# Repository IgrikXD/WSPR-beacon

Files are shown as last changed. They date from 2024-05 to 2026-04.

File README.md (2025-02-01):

# WSPR-beacon

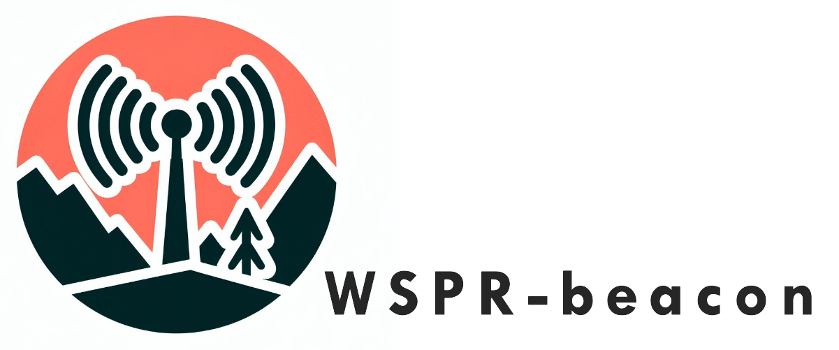
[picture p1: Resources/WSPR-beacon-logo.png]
WSPR-beacon


A small hardware device for transmitting WSPR messages based on the SI5351 IC. The device has a built-in TCXO to eliminate SI5351 frequency drift, a built-in GPS module for operation with active GPS antennas, transmission time synchronization and automatic QTH locator calculation, and a simple amplifier based on a single BS170 transistor ([_PCB version 1.0_](https://github.com/IgrikXD/WSPR-beacon/releases/tag/wspr-beacon-1.0)) or buffer amplifier based on a 74ACT244 IC ([_PCB version 2.0_](https://github.com/IgrikXD/WSPR-beacon/releases/tag/wspr-beacon-pcb-2.0)). PCB is made on based on SMD components and adapted for installation in an aluminum enclosure with dimensions 80 x 50 x 20 mm.

## Project support
[](https://nowpayments.io/donation/wsprbeacon)&nbsp;[](https://www.paypal.com/donate/?hosted_button_id=Q8PRFPXKKSDAQ)&nbsp;[](https://revolut.me/iharygxob)

Your support helps me continue developing open-source projects like [WSPR-beacon](#WSPR-beacon) and [Easy-SDR](https://github.com/IgrikXD/Easy-SDR), while also enabling the creation of new tools that benefit the community.

## Current development progress
[](https://oshwlab.com/igrikxd/wspr-beacon)&nbsp;  
[](https://github.com/IgrikXD/WSPR-beacon/actions/workflows/firmware-build.yml)&nbsp;  

The transmitted WSPR message's correctness was verified by decoding the transmission using a locally located Airspy R2 SDR receiver and the [WSJT-X](https://wsjt.sourceforge.io/wsjtx.html) application. Also, you can see the [results of testing the device during long-distance WSPR message transmission](./Device-test-report.md).

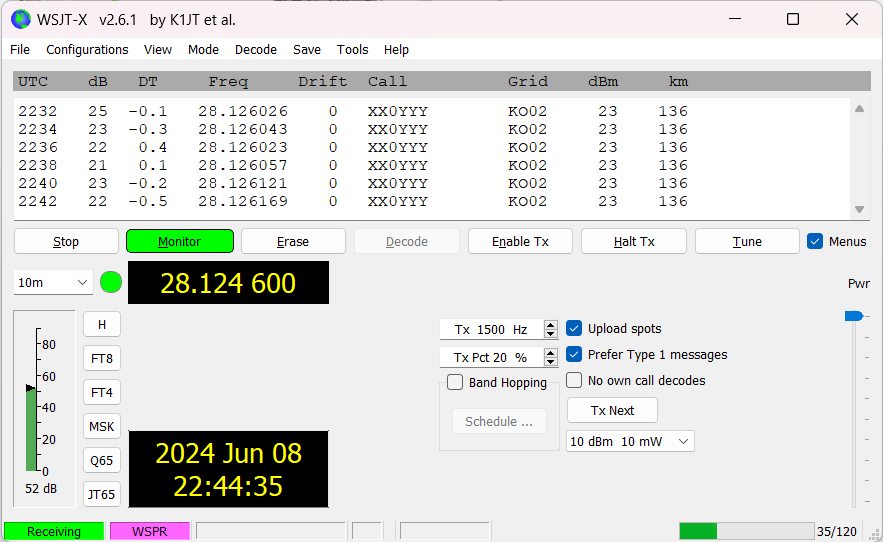
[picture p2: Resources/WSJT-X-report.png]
WSJT-X report


## Basic characteristics of the WSPR-beacon
**RF connectors:** SMA  
**Feed line:** 50 Ohm coaxial cable  
**GPS antenna type:** active, external  
**Maximum output power:** ~23 dBm  
**Supply voltage:** 5V, USB-B, fuse-protected  
**Current consumption:** 65 mA (_GPS antenna not connected_) / 80 mA (_GPS antenna connected_) / 92 mA (_TX mode_)  
**Used PCB Material:** FR-4  
**PCB thickness:** 1.6 mm  
**PCB copper weight:** 1 oz  

## How to use this repository?
The [Firmware](./Firmware/) folder contains software required for the device operation and [firmware instructions](./Firmware/README.md). The [Schematics](./Schematics/) directory contains the device schematic file in _.pdf_ format. The [Gerbers](./Gerbers/) directory contains files necessary for ordering PCB and side covers [fabrication at the factory](https://www.pcbway.com/project/shareproject/WSPR_beacon_2_0_472264d9.html).  

Additionally, you can find information about the [list of required components](./BOMs), [assembly guide](./Assembly-guide.md) and [operating instructions](./Usage-guide.md).

## Resources
[A Little WSPR Beacon (Aren’t They All Little?) – Dave Richards AA7EE](https://aa7ee.wordpress.com/2023/02/26/a-little-wspr-beacon-arent-they-all-little/)  
[Bifilar and trifilar PA](https://qrp-labs.com/ultimate3/u3info/u3sbifilar.html)  
[ESP WSPR – Simple and Inexpensive WSPR Transmitter - Ankara Telsiz ve Radyo Amatörleri Kulübü Derneği](https://antrak.org.tr/blog/esp-wspr-simple-and-inexpensive-wspr-transmitter/)  
[FDIM 2024 LOGIC IC TRANSMITTER CHALLENGE - Ankara Telsiz ve Radyo Amatörleri Kulübü Derneği](https://antrak.org.tr/haberler/fdim-2024-logic-ic-transmitter-challenge/)  
[HarrydeBug/WSPR-transmitters: Arduino firmware for ZachTek WSPR transmitters.](https://github.com/HarrydeBug/WSPR-transmitters/tree/master)  
[K1FM-WSPR-TX - GitHub](https://github.com/adecarolis/K1FM-WSPR-TX)  
[QRP Labs QRSS/WSPR TX Kit](https://qrp-labs.com/images/ultimate3s/assembly_u3s_r3_lt.pdf)  
[WSPR beacon – Projets radio](https://hamprojects.wordpress.com/2019/06/02/wspr-beacon/)  
[WSPR - Signal Identification Wiki](https://www.sigidwiki.com/wiki/WSPR)  

## Who helped me with the development of the project?
Great thanks to [PCBWay](https://pcbway.com) for manufacturing the PCBs for the project as a sponsored contribution.
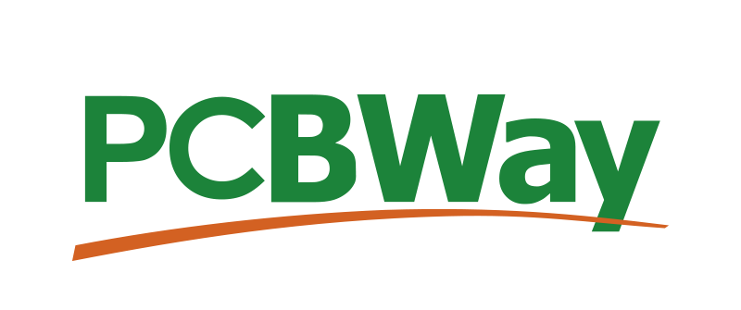
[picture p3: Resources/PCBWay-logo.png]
PCBWay-Logo


## How to contact me?
- E-mail: igor.nikolaevich.96@gmail.com
- Telegram: https://t.me/igrikxd
- LinkedIn: https://www.linkedin.com/in/igor-yatsevich/

You can also [contact me](https://t.me/igrikxd) to purchase preassembled devices.

[BTC-badge]: https://img.shields.io/badge/BTC-Make%20a%20donation-orange.svg?logo=bitcoin&style=for-the-badge
[PayPal-badge]: https://img.shields.io/badge/PayPal-Make%20a%20donation-blue.svg?logo=
[Revolut-badge]: https://img.shields.io/badge/Revolut-Make%20a%20donation-black.svg?logo=
[EasyEDA-badge]: https://img.shields.io/badge/EasyEDA%20WSPR--beacon-tested-greeen.svg?logo=easyeda&style=for-the-badge
[Firmware-build-badge]: https://img.shields.io/github/actions/workflow/status/IgrikXD/WSPR-beacon/firmware-build.yml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

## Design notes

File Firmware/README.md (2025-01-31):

# Firmware instruction

## Select the board:
Open [Arduino IDE](https://www.arduino.cc/en/software), go to "_Tools_" -> "_Board_", then select  "_Arduino Nano_".

## Choose the communication port:
Connect the device to your computer via USB cable. Then, in the "_Tools_" -> "_Port_" menu, select the target COM port.

## Verification of hardware operability after device assembly
After assembling the device, you can upload [firmware for testing the hardware](./wspr-beacon-hardware-test/wspr-beacon-hardware-test.ino).

> [!NOTE]
>This is an optional step, you can skip it. I recommend using this firmware if you encounter issues with the device's functionality when using the main wspr-beacon firmware.

This firmware checks the correctness of the LEDs initialization (_visual inspection_), SI5351 IC initialization, the correctness of the serial connection with the GPS module, and GPS data synchronization.

To get a report on the hardware functionality, [builld and upload](#firmware-building) the [wspr-beacon-hardware-test](./wspr-beacon-hardware-test/wspr-beacon-hardware-test.ino) firmware, open the "_Tools_" -> "_Serial Monitor_" in the Arduino IDE, and turn on the device.

**An example of an hardware test report:**
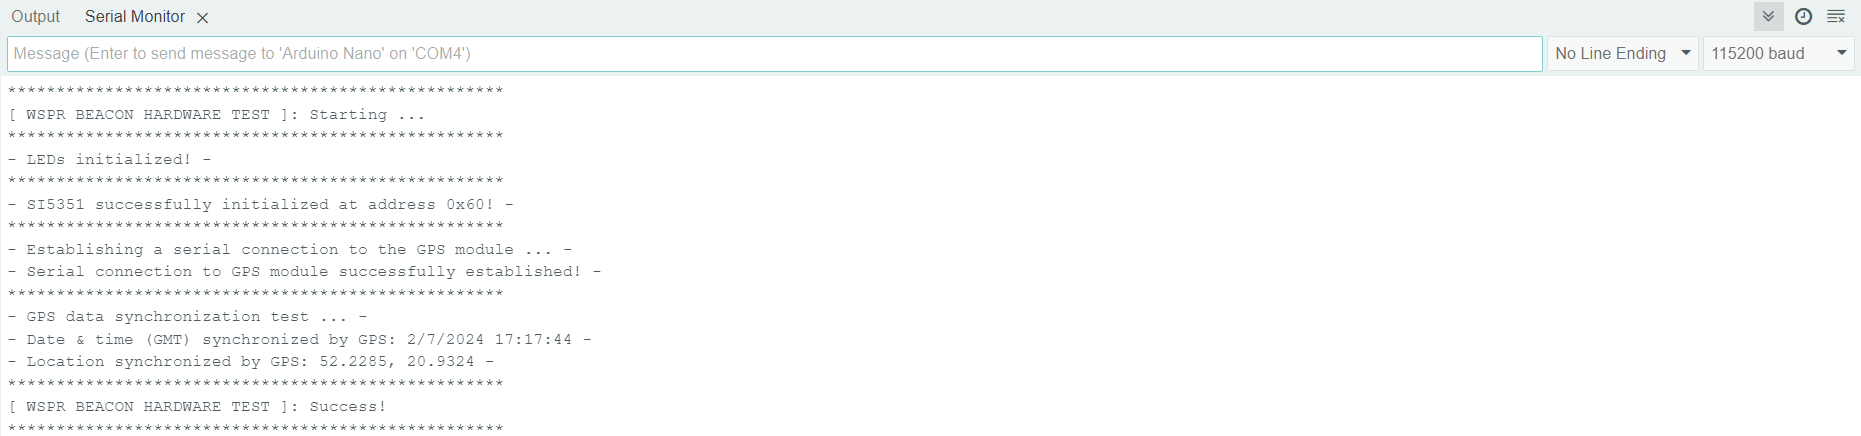
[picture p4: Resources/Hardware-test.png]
Hardware test


## I2C address of the SI5351:
By default, the SI5351 uses address **_0x60_** on the I2C bus. If necessary, you can change the I2C address of the SI5351 according to the datasheet of your instance:
```cpp
#define SI5351_I2C_ADDRESS         0x60
```

## SI5351 calibration:
For correct operation of the device you need to [calibrate](https://github.com/etherkit/Si5351Arduino/tree/master?tab=readme-ov-file#calibration) the SI5351 to calculate the difference between the uncalibrated actual frequency and the nominal output frequency. 

> [!NOTE]
>By default, the sketch for calibrating the SI5351 is set to operate with an output frequency of 10 MHz. If you do not have equipment that can operate at this frequency, you can use an SDR receiver like RTL-SDR.COM and a modified calibration sketch by changing the operating frequency to 28 MHz.

Upload this [sketch](https://github.com/etherkit/Si5351Arduino/blob/master/examples/si5351_calibration/si5351_calibration.ino) into the device and perform the calibration. Calibration is performed once for each pair of SI5351 and TCXO. The resulting calibration value must be changed in the [_wspr-beacon-1.1.ino_](./wspr-beacon-1.1/wspr-beacon-1.1.ino) file: 
```cpp
#define SI5351_CAL_FACTOR          2000
```

## Select the transmission frequency:
Uncomment the line with the band on which you want to perform the WSPR message transmission:
```cpp
// WSPR center frequency in Hz
// #define WSPR_DEFAULT_FREQ       137500ULL    // 0.1375 MHz - 2200m
// #define WSPR_DEFAULT_FREQ       475700ULL    // 0.4757 MHz - 600m
// #define WSPR_DEFAULT_FREQ       1838100ULL   // 1.8381 MHz - 160m
// #define WSPR_DEFAULT_FREQ       3570100ULL   // 3.5701 MHz - 80m
// #define WSPR_DEFAULT_FREQ       5288700ULL   // 5.2887 MHz - 60m
// #define WSPR_DEFAULT_FREQ       7040100ULL   // 7.0401 MHz - 40m
// #define WSPR_DEFAULT_FREQ       10140200ULL  // 10.1402 MHz - 30m
// #define WSPR_DEFAULT_FREQ       14097100ULL  // 14.0971 MHz - 20m
// #define WSPR_DEFAULT_FREQ       18106100ULL  // 18.1061 MHz - 17m
// #define WSPR_DEFAULT_FREQ       21096100ULL  // 21.0961 MHz - 15m
// #define WSPR_DEFAULT_FREQ       24926100ULL  // 24.9261 MHz - 12m
#define WSPR_DEFAULT_FREQ       28126100ULL  // 28.1261 MHz - 10m
// #define WSPR_DEFAULT_FREQ       50294500ULL  // 50.2945 MHz - 6m
// #define WSPR_DEFAULT_FREQ       144490000ULL  // 144.4900 MHz - 2m
```

> [!NOTE]
>At this step you select the center frequency. Each transmission cycle is performed at a randomly selected frequency within a range of +/- 100 Hz from the center frequency.

## Add WSPR message data:
Enter your amateur radio call sign to generate a correct WSPR message:
```cpp
#define WSPR_CALL                 "XX0YYY"
```
There is no need to specify your QTH locator, it will be calculated automatically by _void setQTHLocator()_ function based on actual GPS data.

## Firmware building:
Before building the firmware using Arduino IDE, you **need to install all the required dependencies**. You can automatically install all the necessary dependencies using Arduino CLI. Download and extract the [latest version of Arduino CLI](https://downloads.arduino.cc/arduino-cli/arduino-cli_latest_Windows_64bit.zip) into the directory containing the firmware you want to build. Run the following command to automatically download dependencies and build the firmware:
```powershell
./arduino-cli compile --export-binaries
```

## Upload an firmware:
Click the "_Upload_" button in the Arduino IDE to build and upload firmware to the device.

Alternatively, you can upload the precompiled _.hex_ file (_located in the build/arduino.avr.nano directory_) directly to the device using Arduino CLI:
```powershell
./arduino-cli upload --input-file build/arduino.avr.nano/<FIRMWARE_NAME>.hex --port <TARGET_PORT> --verify
```

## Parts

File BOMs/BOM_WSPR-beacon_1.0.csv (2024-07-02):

ID | Name | Designator | Footprint | Quantity | Manufacturer Part | Manufacturer | Supplier | Supplier Part
1 | CR1220-2 | B1 | BAT-SMD_CR1220-2 | 1 | CR1220-2 | Q&J | LCSC | C70381
2 | 100n | C1,C6,C7,C8,C11,C13,C15,C16,C19 | 0805 | 9 | CC0805JRX7R9BB104 | YAGEO | LCSC | C111492
3 | 10u | C2 | CASE-A_3216 | 1 | TAJB107M010RNJ | Kyocera AVX | LCSC | C7171
4 | 100u | C3,C18 | CASE-B_3528 | 2 | TAJB107M010RNJ | Kyocera AVX | LCSC | C7196
5 | 22p | C4,C5,C9,C10 | 0805 | 4 | CC0603JRNPO9BN220 | YAGEO | LCSC | C105620
6 | 10u | C12 | 0805 | 1 | CL21A106KOQNNNE | Samsung Electro-Mechanics | LCSC | C1713
7 | 100p | C14 | 0805 | 1 | C2012C0G2A101JT000N | TDK | LCSC | C76633
8 | 10n | C17,C20 | 0805 | 2 | 0805B103J500NT | Guangdong Fenghua Advanced Tech | LCSC | C24666
9 | PTC, 600 mA, 6V | F1 | F0805 | 1 | BSMD0805-030-6V | BHFUSE | LCSC | C22378354
10 | TX OUT | J1 | SMA-EDGE | 1 | BWSMA-KE11 | BAT WIRELESS | LCSC | C5250058
11 | GPS ANT | J2 | SMA-EDGE | 1 | BWSMA-KE11 | BAT WIRELESS | LCSC | C5250058
12 | 47n | L1 | 0805 WITHOUT MASK | 1 | FHW0805UC047JGT | FH (Guangdong Fenghua Advanced Tech) | LCSC | C113330
13 | RED | LED1 | LED-0805 | 1 | F.0805.00006/P2-0805R1TS2-08T-002 | TUOZHAN | LCSC | C7496834
14 | GREEN | LED2,LED3 | LED-0805 | 2 | NCD0805G1 | Foshan NationStar Optoelectronics | LCSC | C84260
15 | BS170 | Q1 | TO-92-3_L4.9-W3.7-P1.27-L | 1 | BS170 | onsemi(安森美) | LCSC | C111691
16 | 1M | R1 | 0805 | 1 | RC0805FR-071ML | YAGEO | LCSC | C107700
17 | 10k | R2 | 0805 | 1 | 0805WAD1002T5E | Uniroyal Elec | LCSC | C169071
18 | 1k | R3 | 0805 | 1 | 0805W8F1001T5E | UNI-ROYAL(Uniroyal Elec) | LCSC | C17513
19 | 3.3k | R4,R5,R8 | 0805 | 3 | 0805W8F3301T5E | UNI-ROYAL(Uniroyal Elec) | LCSC | C26010
20 | 4.7k | R6,R7 | 0805 | 2 | 0805W8F4701T5E | UNI-ROYAL(Uniroyal Elec) | LCSC | C17673
21 | 3.3k | R9 | RES-ADJ-SMD_VG039NCH | 1 | VG039NCHXTB332 | HDK(Hokuriku Elec Industry) | LCSC | C128554
22 | MTS-101/102-C3 | SW1 | MTS-102-C3 | 1 | 1MS1T2B4M6QES | Dailywell | LCSC | C545199
23 | FT37-43-Bifilar 10T | T1 | BIFILAR_FT37-43 | 1 | 5943000201 | Fair-Rite (Amidon) | RF Microwave | FT-37-43
24 | LM1117IMPX-3.3/NOPB | U1 | SOT-223_L6.5-W3.5-P2.30-LS7.0-BR | 1 | LM1117IMPX-3.3/NOPB | TI(德州仪器) | LCSC | C23984
25 | CH340G | U2 | SOIC-16_150MIL | 1 | CH340G | Jiangsu Qin Heng | LCSC | C14267
26 | ATMEGA328P-AU | U3 | TQFP-32_7X7X08P | 1 | ATMEGA328P-AU | Microchip Tech | LCSC | C14877
27 | ATGM336H-5N31 | U4 | GPSM-SMD_ATGM336H-TR | 1 | ATGM336H-5N31 | ZHONGKEWEI | LCSC | C90770
28 | 25MHz TCXO | U5 | OSC-SMD_4P-L3.2-W2.5-BL_7Q26000001 | 1 | SX3T25.000B010J020S | Shenzhen SCTF Elec | LCSC | C5180004
29 | Si5351A-A-GT | U6 | MSOP10 | 1 | SI5351A-B-GTR | SKYWORKS/SILICON LABS | LCSC | C504891
30 | USB-B | USB1 | USB TYPE B | 1 | C46392 | Jing Extension of the Electronic Co. | LCSC | C46392
31 | 12MHz | X1 | CRYSTAL-SMD_4P-L3.2-W2.5-BL_SIT8008BI | 1 | CF4012M00020001 | HUAXIN(华昕) | LCSC | C7294551
32 | 16MHz | X2 | CRYSTAL-SMD_4P-L3.2-W2.5-BL_SIT8008BI | 1 | CF4016M00012001 | HUAXIN(华昕) | LCSC | C7294559

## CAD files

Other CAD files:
Enclosure-models/WSPR-beacon-side-covers.dwg

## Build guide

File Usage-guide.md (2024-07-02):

# WSPR-beacon usage guide

## Device preparation
[Assemble the device](./Assembly-guide.md) and [upload the firmware](./Firmware/). Connect active GPS antenna, antenna for WSPR message transmission and USB-B cable for device power supply.  

> [!NOTE]
>It is recommended to use full-size antennas for a specific transmission range, as their efficiency is significantly superior to that of wideband and compact antennas. Also, it is recommended to use bandpass filters that suppress unwanted signals outside the operating range (the SI5351 emits unwanted harmonics along with the main signal emission at the operating frequency).

## Device usage
The device operates in fully automatic mode. Turn on the device by switching the **_SW1_** toggle switch position. After switching on the device the **_green LED (ON)_** should light up, which means that the device is working correctly and the initialization process has started. 

### Hardware initialization
Initialization of the hardware is performed in the _void setup()_ function and is executed only once, when the device is started.  

By default, the SI5351 is initialized at I2C address 0x60. If no device is detected at this address, an initialization error is indicated by the LED (_the **red LED (TX)** blinks three times_) and the device subsequently restarts. **If you encounter any problems at this stage - make sure that your SI5351 instance really has I2C address 0x60!** If necessary, you can [change the value of the I2C address of the SI5351](https://github.com/IgrikXD/WSPR-beacon/tree/master/Firmware#i2c-address-of-the-si5351) in the firmware source code.

The GPS module used in the device operates using a software-implemented serial port. Initialization of the GPS module starts with checking if any information is available from the GPS receiver on the virtual serial port. If no data is received within "_GPS_INIT_MAX_TIME_" - an GPS module initialization error is indicated by the LED (_the **red LED (TX)** blinks three times_) and the device will be rebooted. 

If the connection is successfully initialized, date and time synchronization is performed based on the data received from the GPS module. The device performs "_GPS_SYNC_ATTEMPTS_" attempts to synchronize GPS data with a delay of "_GPS_SYNC_DELAY_". If all synchronization attempts fail, an GPS data synchronization error is indicated by the LED (_the **red LED (TX)** blinks three times_) and the device is rebooted.  

> [!WARNING]
>The device will not transmit WSPR messages until the time and coordinates are synchronized!  

Successful completion of GPS data synchronization is signaled by a **_green LED (GPS)_**, after which the device proceeds to generate a buffer containing a WSPR message for transmission.

The calculation of your QTH locator is performed once during the device initialization based on current GPS data. The QTH locator is calculated during the execution of the _void encodeWSPRMessage(const TinyGPSPlus& gpsDataObj)_ function using the _void setQTHLocator(const TinyGPSPlus& gpsDataObj, char qthLocator[])_ function and is immediately written to the buffer responsible for forming the transmitted WSPR message. **Subsequently, during the operation of the device, the QTH locator is not updated!**  

### WSPR message transmission
Transmission of WSPR messages is performed in an infinite loop _void loop()_ every even minute (_00:00, 00:02, 00:04, ..._). **Each transmission cycle is executed at a randomly selected frequency within the range of +/- 100 Hz from the center operating frequency.** During the WSPR message transmission, the **_red LED (TX)_** lights up and goes out immediately after the transmission is completed. After completion of the transmission cycle, the device re-synchronizes the time based on the current GPS data values.

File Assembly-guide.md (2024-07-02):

# Assembly guide

## PCB requirements
When manufacturing the PCB, use FR-4 material with a thickness of 1.6 mm and a copper weight oequal to 1 oz. Although this is not the best material for radio frequency equipment, it is the most popular and widely available. The use of FR-4 material is necessary to ensure the wawe impedance of the RF line is 50 ohms. Failure to meet this requirement will result in additional signal loss during device operation. The impedance calculations were performed for a material with a dielectric constant Er = 4.6 (FR-4) using the [Saturn PCB Design V7.08](http://www.saturnpcb.com/pcb_toolkit/) toolkit.

## Requirements for Atmega328

When using Atmega328 distributed as individual electronic components, you will encounter a firmware upload error:
```log
avrdude: stk500_recv(): programmer is not responding 
avrdude: stk500_getsync() attempt 1 of 10: not in sync: resp=0x88
```

This is because **Atmega328 chips distributed as individual electronic components do not have a built-in bootloader** – they are completely blank chips, making it impossible to upload firmware via the Arduino IDE. Since the WSPR beacon PCB does not have an ISP interface, **you need to use an Atmega328 chip with a pre-flashed bootloader when assembling the device**. The best solution in this situation might be to move the Atmega328 chip from a ready-made Arduino Nano board. Such a chip already has a pre-flashed bootloader, allowing you to upload the WSPR beacon firmware without any problems.

## Winding a bifilar transformer
For winding a bifilar transformer, I recommend you use the instructions from [QRP-Labs: "10-turn bifilar-winding option"](https://qrp-labs.com/images/ultimate3s/assembly_u3s_r3_lt.pdf).  

**The only difference lies in the method of soldering the bifilar transformer on the PCB:** you need to solder the end of the primary winding to the beginning of the secondary winding - this will be one of the transformer leads, which is soldered as the central contact of the transformer on the PCB.

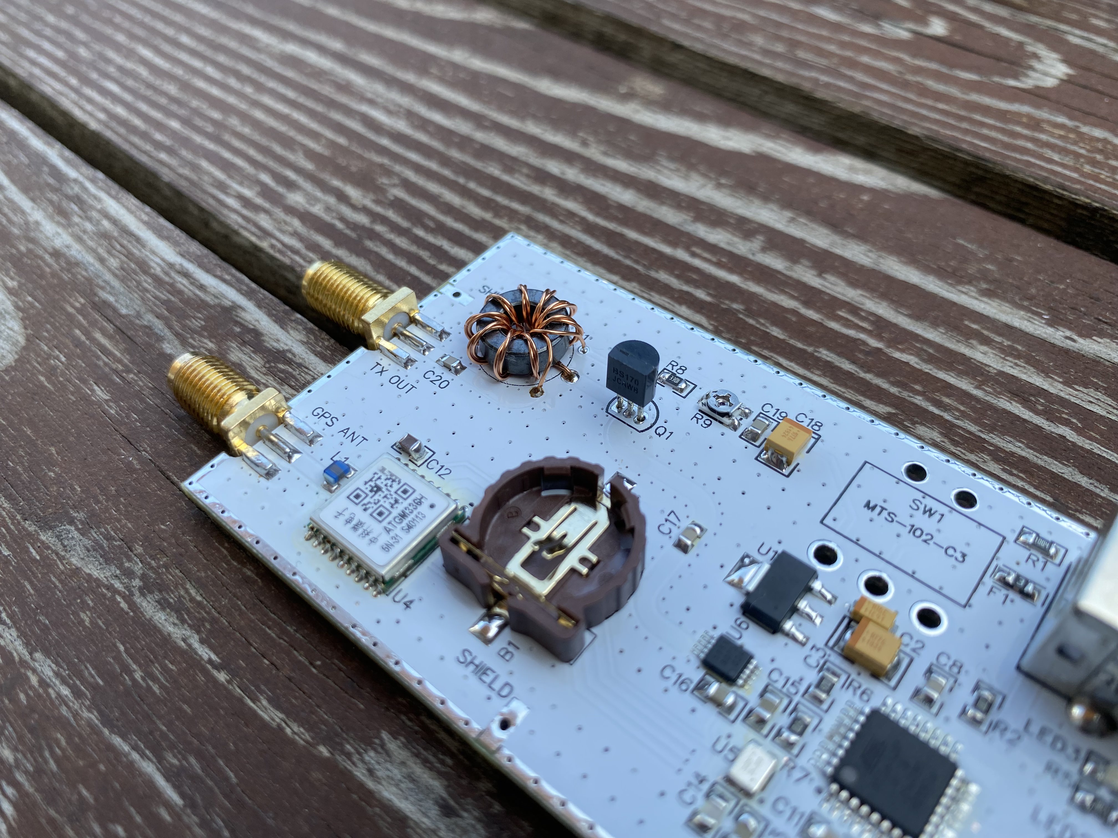
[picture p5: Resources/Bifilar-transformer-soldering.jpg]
Bifilar transformer soldering
  

## Installing the PCB in the aluminum enclosure

To assemble the device, an aluminum case with dimensions 80 x 50 x 20 mm is used.

Install the PCB in one part of the enclosure by placing it on the appropriate chassis. Screw on the side covers of the chassis and tighten the nuts on the SMA connectors - this will secure the PCB and allow you to mark the locations for cutting the holes for the SW1 toggle switch. Take the SW1 toggle switch and place it in the mounting location on the PCB. The area where the toggle switch contacts the side of the case must be milled (_you can use a 6mm round file_) so that the toggle switch can be positioned and soldered to the PCB.  

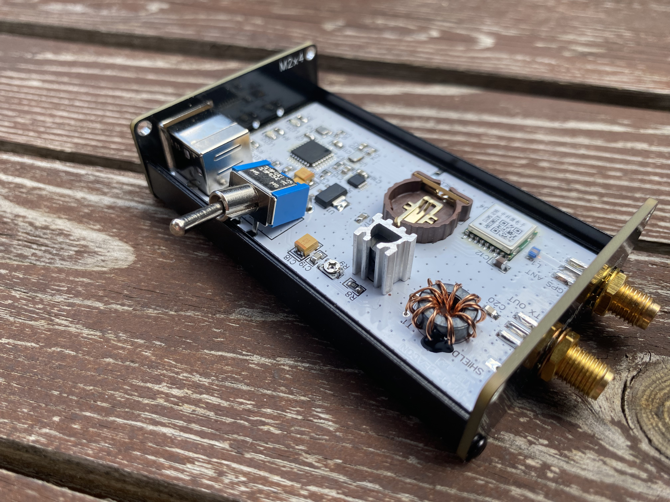
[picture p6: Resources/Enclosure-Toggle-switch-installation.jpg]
Toggle switch installation
  

Mark the same point on the top of the aluminum enclosure.  

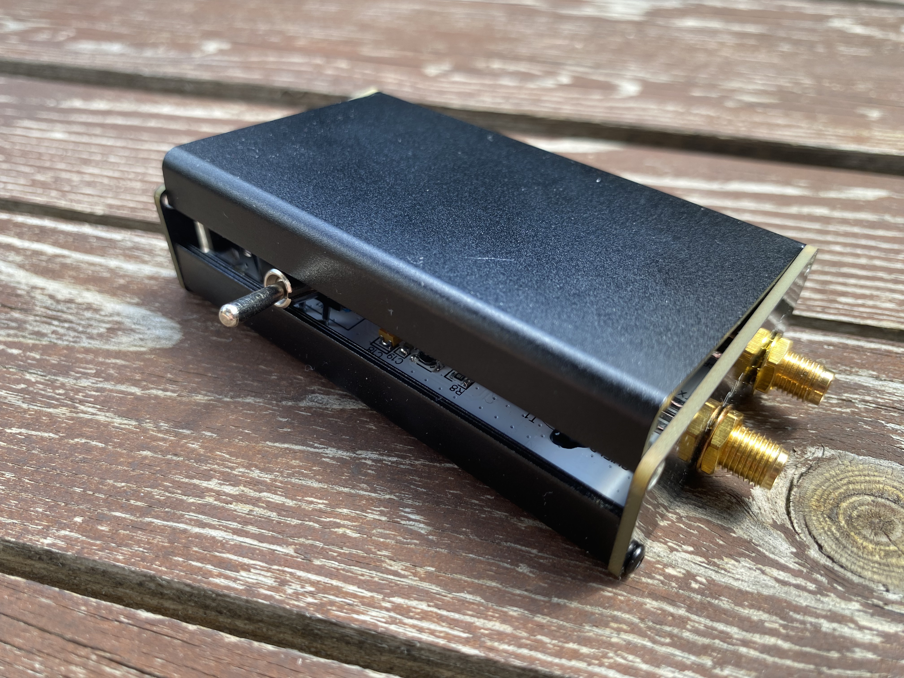
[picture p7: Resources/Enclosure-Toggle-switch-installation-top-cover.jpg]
Toggle switch installation, top cover
  

Unscrew the side covers of the enclosure, remove the PCB and use a file to cut the hole for the toggle switch to the correct depth. After cutting, put the PCB back into the case and check how freely the toggle switch fits into the cut-out hole. If you are unable to install the toggle switch correctly, repeat the above steps until optimal results are achieved.  

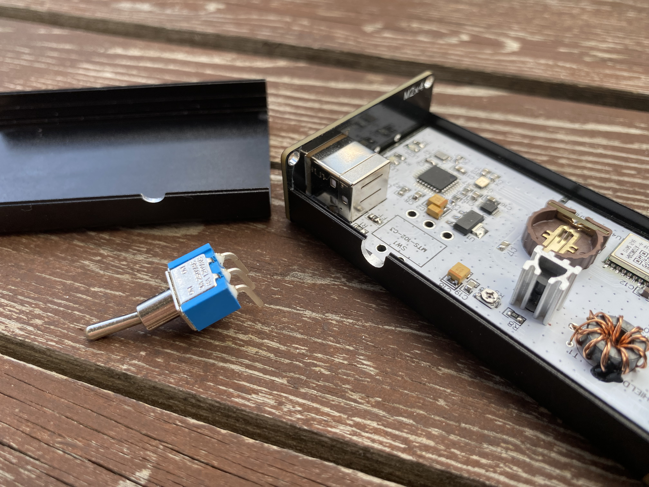
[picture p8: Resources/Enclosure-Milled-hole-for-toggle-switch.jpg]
Milled hole for toggle switch
 

Insert the PCB back into the enclosure, screw on the side covers of the aluminum enclosure, and tighten the nuts on the SMA connectors, then solder the SW1 toggle switch.

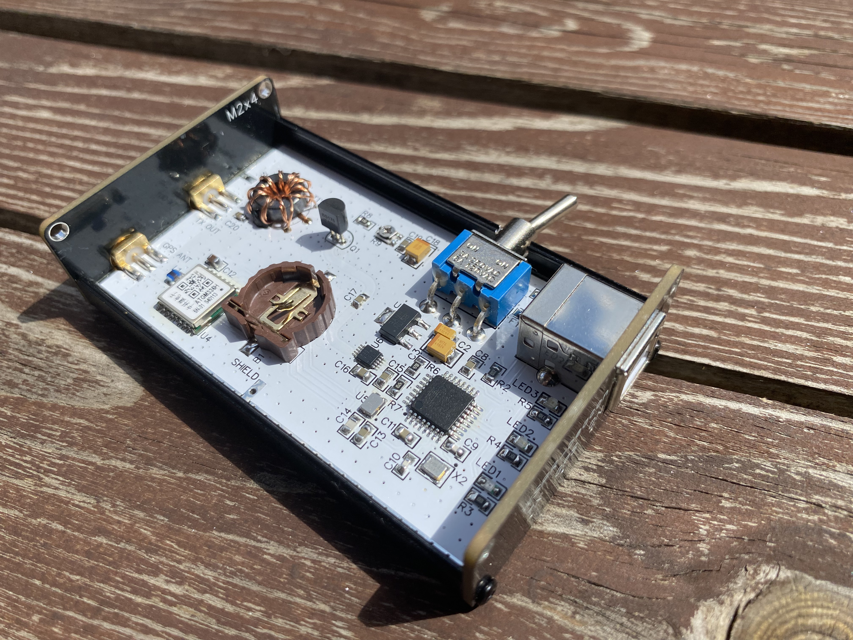
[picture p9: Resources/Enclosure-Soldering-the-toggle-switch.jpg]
Soldering the toggle switch
  

After soldering clean the PCB to remove any flux residues. Screw the top cover of the aluminum enclosure. Now the device is ready to work.

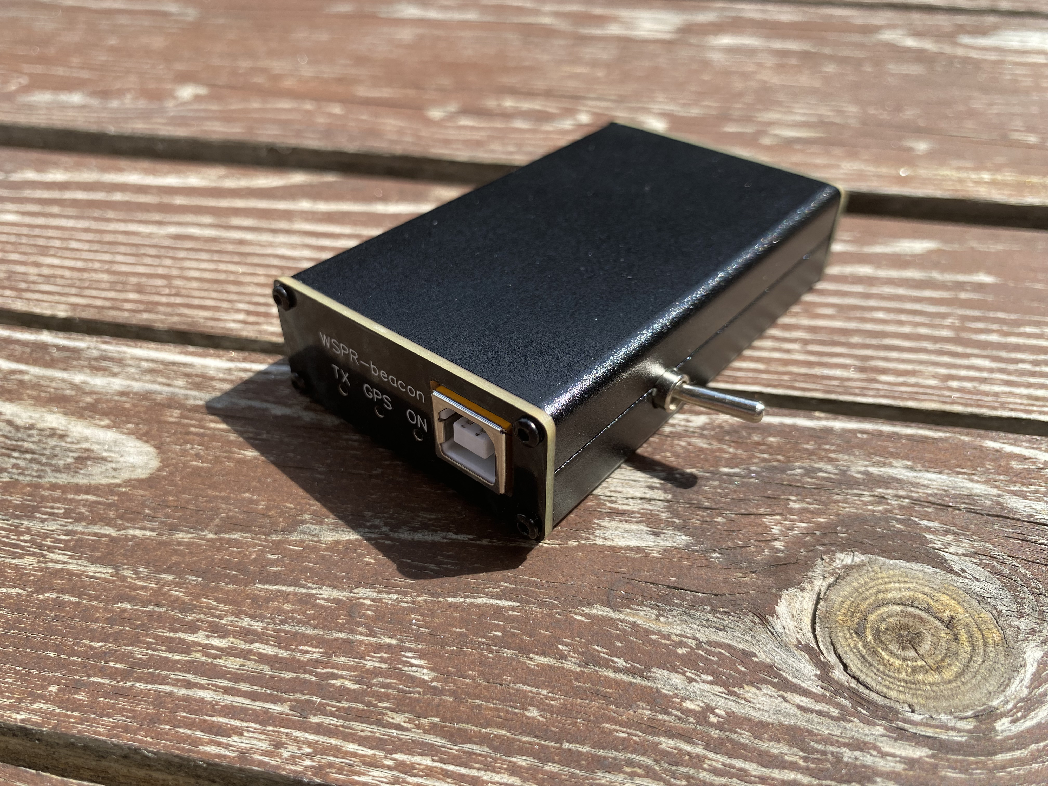
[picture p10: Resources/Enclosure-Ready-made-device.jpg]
Ready-made device
  

## Adjusting the output amplifier
> [!NOTE]
> Only applicable for [PCB version 1.0](https://github.com/IgrikXD/WSPR-beacon/releases/tag/wspr-beacon-1.0)!

To adjust the output amplifier, I recommend you use the instructions from [QRP-Labs: "PA bias set-up"](https://qrp-labs.com/images/ultimate3s/assembly_u3s_r3_lt.pdf).

For additional cooling of the BS170 transistor, you can use an off-the-shelf aluminum heatsink for TO-92 package transistors.  

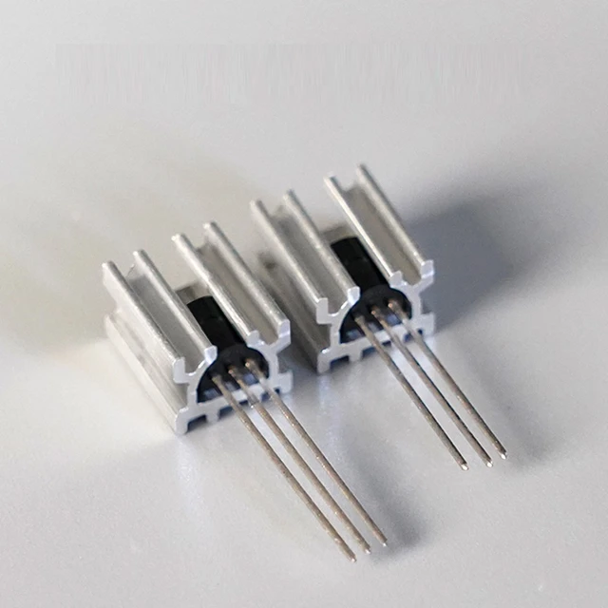
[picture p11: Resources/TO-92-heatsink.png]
TO-92 heatsink


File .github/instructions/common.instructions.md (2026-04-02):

---
applyTo: "**/*"
---

# Project description
The project is an open implementation of a hardware-software platform used for transmitting amateur WSPR messages.

The project is divided into the following main logical directories:
- `App/` - contains the source code of the **BEACON.App** user application, used with devices based on the **ESP32-C3 SoC**. It also includes integration tests, unit tests, and build documentation for different operating systems.
- `Firmware/` - contains firmware-related files for devices based on the **ATmega328P MCU** and the **ESP32-C3 SoC**. For ATmega328P MCU, it includes firmware source code, build documentation, and end-user documentation. For ESP32-C3 SoC, it contains firmware version metadata and download links for binary images. The ESP32-C3 SoC firmware is proprietary and stored in a separate private repository that is not accessible to end users.
- `PCB/` - contains Gerber manufacturing files, schematics, bills of materials (_BOM_), and manual assembly instructions for a specific device revision.
- `Resources/` - contains graphical assets used in the project documentation.

The project is developed using a modular architecture with a clear separation of responsibilities between individual components.

# Critical rules
- **Never fabricate.** Do not invent information, do not make assumptions, and do not speculate about code, APIs, or functionality that you have not explicitly verified by reading the documentation files or performing searches.
- **Data-driven development.** All created solutions or responses must be based on factual data from technical documentation or search results.
- **Ask if something is unclear.** If any information is ambiguous, requires confirmation, or has multiple possible interpretations, clarify the points you need before continuing.
- **Availability of MCP.** If the required MCP plugin is unavailable, explicitly inform the user and provide instructions on how to enable it.
- **eFuse Safety.** Writing to eFuse is a permanent operation. Before suggesting any command that modifies eFuses (e.g., via espefuse.py), explicitly warn the user that this action is irreversible and could brick the device if keys or parameters are incorrect.
- **Look before you leap.** Before implementing a new functionality, search the `App/` (_if changes requested for the BEACON.App_) or `Firmware/` (_if changes requested for the firmware_) directory for existing implementations. Reuse existing modular components to maintain architectural consistency.

# Related instruction files
- [beaconapp.instructions.md](./beaconapp.instructions.md) — **BEACON.App** architecture, threading model, logging, testing conventions, and auxiliary tools (_applies to `App/**`_).
- [firmware.instructions.md](./firmware.instructions.md) — Firmware source code structure and build environment for ATmega328P MCU based and ESP32-C3 SoC based devices (_applies to `Firmware/**`_).
- [python.instructions.md](./python.instructions.md) — Python naming conventions, error handling, code formatting, docstrings, import ordering, type hints, and best practices (_applies to `**/*.py`_).

# Auxiliary tools
- **MCP (Model Context Protocol):** Use the MCP plugin to access multiple contexts of information, including project documentation, codebase, and external resources. Always specify the context you are referring to when providing information or asking questions. Available MCP servers:
  - **Context7:** Provides up-to-date technical documentation for libraries and APIs used in the project. For any question regarding relevant available API or protocol specifics, you must use this tool. Do not rely on your internal training data for API specs, as API revisions may vary.
  - **GitHub:** Provides access to GitHub repository operations such as managing issues, pull requests, branches, releases, and code search. For any tasks involving GitHub repository interactions, you must use this tool. When creating or updating pull requests and issues, always assign them to the author and apply appropriate [labels](https://github.com/IgrikXD/WSPR-beacon/labels). Refer to [CONTRIBUTING.md](../../CONTRIBUTING.md) for detailed project contribution guidelines, including rules for opening issues, submitting pull requests, branch naming conventions, and code review process.

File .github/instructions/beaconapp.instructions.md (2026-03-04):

---
applyTo: "App/**"
---

> Python coding conventions (_naming, error handling, formatting, type hints_) are defined in [python.instructions.md](./python.instructions.md).

## BEACON.App source code
The **BEACON.App Python source code** is located in the `App/` directory and is responsible for:
- Supporting communication between the hardware device (_WSPR-beacon_) and the desktop user application (_BEACON.App_) via USB (_Serial_) or Wi-Fi (_WebSocket_) connections using control commands in JSON format.
- Generating valid JSON control commands sent to the device (_WSPR-beacon_) to set the active transmission mode, run self-checks, and configure device parameters (_calibration, Wi-Fi connection_).
- Providing a device firmware update mechanism both via USB and through OTA updates.
- Ensuring the reliability of the user application by implementing integration and unit tests to verify the functionality of implemented features.

The application source code is organized into the following subpackages within `App/beaconapp/`:
- `transports/` - transport layer implementations.
- `ui/` - user interface widgets and graphical resources.
- `tests/` - test suite, split into `unit/` and `integration/` subdirectories.

**BEACON.App** is designed to work only with devices based on the **ESP32-C3 SoC**. Devices based on the **ATmega328P MCU** are not supported!

### Build environment
- **Build system (_GitHub Actions_):** PyInstaller.
- **Build configuration file (_Linux, GitHub Actions_):** `.github/workflows/app-build-linux.yml`.
- **Build configuration file (_Windows, GitHub Actions_):** `.github/workflows/app-build-windows.yml`.
- **Test configuration file (_GitHub Actions_):** `.github/workflows/app-tests.yml`.
- **Python standard:** 3.12.

# Async and threading
The application uses a two-thread architecture:
- **Main thread** runs the Tkinter/customtkinter event loop (_UI_). All UI manipulations must happen on this thread.
- **Asyncio thread** is a dedicated daemon thread that owns an asyncio event loop and calls `loop.run_forever()` to handle USB (_Serial_) and Wi-Fi (_WebSocket_) transport I/O.

Communication between threads:
- **Main -> asyncio**: Use `asyncio.run_coroutine_threadsafe()` to schedule coroutines, or `loop.call_soon_threadsafe()` for synchronous calls into the event loop.
- **Asyncio -> UI**: Transport layers decode incoming JSON messages and invoke registered callback handlers via `Device._call_handlers()`. Callbacks that update UI must use `widget.after(0, lambda: ...)` to marshal the call onto the main thread.

The UI registers its callbacks for device message types via `Device.set_device_response_handlers()`, forming a message-driven architecture where the `Device` class acts as the bridge between transports and UI.

Threading primitives:
- Use `asyncio.Queue` for outgoing message passing between the main thread and the asyncio transmit loop. `asyncio.Queue` is not thread-safe; the main thread must enqueue items via `loop.call_soon_threadsafe(queue.put_nowait, item)` to ensure the operation executes on the asyncio thread.
- Use `threading.Lock` for protecting shared state (_e.g., connection state_).
- Use `threading.Event` for cross-thread synchronization (_e.g., waiting for the event loop to start_).
- Use `threading.Thread(target=..., daemon=True)` for background work dispatch (_e.g., USB firmware update_).
- Any new functionality that may block the UI thread or the asyncio thread must be executed in a separate thread to prevent freezing the interface or stalling transport I/O.

# Logging
- Use the logging facade in `logger.py` (_`log_ok`, `log_error`, `log_warning`, `log_rx_message`, `log_tx_message`_) instead of calling the `logging` module or `print()` directly.
- Debug mode is controlled by the `--debug` CLI argument.

# Testing conventions
- Any new functionality must be covered by unit tests. Features that involve hardware interaction must also be covered by integration tests.
- Use **pytest** as the primary test framework.
- Mark every unit test with `@pytest.mark.unit` and every integration test with `@pytest.mark.integration`.
- Use `@pytest.mark.parametrize` for data-driven tests. Place `@pytest.mark.parametrize` **before** the marker decorator (_e.g., `@pytest.mark.unit`_) in the decorator stack.
- Use `tmp_path` (pytest built-in) for temporary file operations in tests. Use `os.path.dirname(__file__)` for loading test fixture files.
- Gate integration tests with `@pytest.mark.skipif(not find_device(), reason="...")` when they require a connected hardware device.
- Add Google-style docstrings to test functions to describe what is being verified.
- Use `pytest.raises()` with an optional `match=` parameter for exception testing.
- Use **pytest-cov** for measuring test coverage. Run coverage with `python -m pytest --cov=beaconapp --cov-config=pytest.ini`. Coverage configuration is defined in `App/pytest.ini` and excludes test files, `__init__.py`, and `main.py` (_application entry point_) to focus on business logic coverage.

# Auxiliary tools
- **pip**: Package manager for installing project dependencies. Runtime dependencies are listed in `App/requirements.txt`, development dependencies in `App/requirements-dev.txt`.
- **flake8**: The project uses flake8 with plugins for linting, code style enforcement, cyclomatic complexity checking, and static analysis (_bugbear, builtins, comprehensions, eradicate, simplify_). Refer to the `App/.flake8` file for the configuration.

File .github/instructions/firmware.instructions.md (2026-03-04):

---
applyTo: "Firmware/**"
---

## Firmware source code
The firmware source code is located in the `Firmware/` directory and is split into separate subdirectories depending on the device architecture used.

### ATmega328P MCU-based devices
The firmware source code is located in the `Firmware/ATmega328P-based/` directory and is responsible for:
- Generating a user-predefined WSPR message based on the amateur radio callsign and the transmit power in dBm, for subsequent transmission on a predefined frequency.
- Calculating the QTH locator used when forming the WSPR message using data received from the onboard GPS module.
- Synchronizing the transmission timing of WSPR messages using data received from the onboard GPS module.
- Adding a random transmit frequency offset to prevent collisions with other WSPR transmitters operating in the same area.
- Indicating possible errors via the built-in LED indicators.
- Testing the functionality of the device's internal components and presenting the test results to the user using a separately flashed firmware image.

Devices based on the ATmega328P MCU do not support reconfiguration during operation. To apply new operating parameters (_amateur radio callsign, transmit power, transmission frequency_), the user must manually modify the firmware source code, rebuild it, and re-flash the device.

#### Build environment
- **Build system (_GitHub Actions_):** Arduino CLI.
- **Build configuration file (_GitHub Actions_):** `.github/workflows/firmware-build.yml`.

### ESP32-C3 SoC-based devices
The firmware is distributed to end users only in a signed and pre-encrypted form, which implies that it can be executed only on hardware devices that have explicitly provisioned Secure Boot v2 signing and Flash Encryption AES-XTS keys stored in the ESP32-C3 SoC eFuse.

In turn, the `Firmware/ESP32C3-based/` directory contains a `latest-stable.json` file with information about the current firmware version, download links to the binary files (_used for firmware updates via the BEACON.App application over USB and via the OTA mechanism_), and a SHA-256 checksum for validating the provided binary images.

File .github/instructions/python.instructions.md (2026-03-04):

---
applyTo: "**/*.py"
---

# Naming conventions
- Use `snake_case` for variables, functions, and methods.
- Use `ALL_CAPS` for module-level constants (_e.g., `LOCK_DIR`, `API_ENDPOINT`_).
- Use `PascalCase` for classes and enums (_e.g., `SomeClass`, `SomeEnum`_).
- Use single-underscore prefix (`_`) for private methods and instance attributes (_e.g., `_some_function`, `self._some_attribute`_).
- Use double-underscore prefix (`__`) for class-level private constants with name mangling (_e.g., `__SOME_VALUE`, `__SOME_VALUE_MAX_SIZE`_).

# Error handling
- Use custom exception classes nested inside the relevant class (_e.g., `SomeClass.SomeSpecificError`_) for domain-specific errors.
- Use `ValueError` for input validation failures.
- Use `try`/`except` with specific exception types. Log errors instead of re-raising (_in async/callback contexts_).
- Use `contextlib.suppress()` for non-critical exceptions that should be silently ignored (_e.g., `contextlib.suppress(OSError)`_).

# Code formatting
- Follow PEP 8 style guide for Python code formatting.
- Use blank lines to separate logical blocks of code for better readability.
- Use 4 spaces per indentation level. Do not use tabs.

# Comments
- Use Google-style docstrings (_triple-quoted strings_) to document functions and classes. Include `Args:`, `Returns:`, `Yields:`, and `Raises:` sections where applicable.
- Class-level docstrings are required for all classes, including widgets and test modules. Method-level docstrings are required for all public and private methods that perform non-trivial operations.
- For widget `__init__` methods that accept external dependencies (_e.g., `parent`, `device`, `config`_), add a docstring with an `Args:` section describing each parameter.
- Document class-level private constants using regular `#` comments placed above the constant. Do not use standalone triple-quoted string literals inside a class body for this purpose - they are not attached to the following assignment, do not appear in generated documentation, and create an unused string constant at class creation time.
- Use inline comments sparingly to explain non-obvious code sections. Avoid stating the obvious.
- Keep comments up to date with code changes to prevent confusion.
- Avoid using comments to disable code.

# Import ordering
- Follow PEP 8 import grouping: standard library first, then third-party, then local (`modulename.*`). Separate each group with a blank line.
- Within each group, place bare `import` statements before `from ... import` statements, each sub-group sorted alphabetically.

# Type hints
- Use type hints for function parameters and return types where applicable.
- Use `typing` module types (_`Optional`, `Dict`, `List`, `Set`, `Callable`, `Any`_) for complex annotations.
- Use modern union syntax (_`X | Y`_) where applicable.

# Best practices
- Use context managers (_`with` statements_) for resource management (_e.g., file handling, serial connections, threading locks_).
- Use list comprehensions and generator expressions for concise and efficient code where appropriate.
- Avoid using mutable global variables. Use module-level `ALL_CAPS` constants for configuration values.
- Always specify `encoding="utf-8"` when opening text files.
- Use f-strings for string formatting instead of `%` or `.format()`.
- Use `@dataclass` for data containers with manual `to_json()`/`from_json()` serialization methods. Dataclass fields must be typed.
- Use `Enum` for value enumerations.
- Use `ABC` + `@abstractmethod` for abstract interfaces.
- Use `@staticmethod` for utility methods that do not access instance or class state (_e.g., `Widgets` factory, `DataValidation` validators_).
- Use `@classmethod` for factory/deserialization methods (_e.g., `from_json`_).
- Use `widget.after(0, lambda: ...)` for thread-safe Tkinter/customtkinter UI updates from non-main threads.

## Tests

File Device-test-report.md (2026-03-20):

# WSPR-beacon device test report

This section provides information about the device's performance during long-distance WSPR message transmission. Data on transmitted and decoded WSPR messages are taken from the [WSPR Rocks!](http://wspr.rocks/)

For each transmission range, a visualized report with a list of all spots is available. To view the visualization, click on the distance in the "_Max distance to receiver_" column.

> [!NOTE]
>During testing of the device, the antenna used was tuned to the resonant frequency using the NanoVNA vector network analyzer.  
>
>**The efficiency of an antenna's performance largely depends on its installation conditions!** In addition to tuning the antenna to achieve the minimum SWR value, the quality of transmission is also influenced by: the height of the antenna installation, the orientation of the antenna in space, the presence of dense urban development with a large amount of electromagnetic interference, and the presence of dense forests absorbing emitted radio waves. **Please, when installing the antenna, to achieve maximum performance, consider all possible factors affecting the efficiency of radio transmission!**

**Power source used:** Mi Power Bank Pro PLM07ZM  
**Coordinates of the antenna installation site:** [52.1958, 20.7581](https://maps.app.goo.gl/dVwvhpxdYiYVqSht5)

### [PCB version 1.0](https://github.com/IgrikXD/WSPR-beacon/releases/tag/wspr-beacon-1.0) with BS170 field-effect transistor amplifier:

| Firmware version | TX frequency | TX time (CET) | PA bias | Used antenna | SNR | Drift | Max distance to receiver |
|---|---|---|---|---|-----|---|---|
| 1.0 | 5.2887 MHz | 21:02 - 21:32 | 2.508V  | [Windcamp Gipsy] | -22 | 0 | 3898 km |
| 1.0 | 7.0401 MHz | 19:04 - 19:34 | 2.508V  | [Windcamp Gipsy] | -16 | 0 | 2849 km |
| 1.0 | 10.1402 MHz  | 17:32 - 18:02 | 2.508V  | [Windcamp Gipsy] | -4  | 0 | 2849 km |
| 1.0 | 14.0971 MHz  | 15:10 - 15:40 | 2.508V  | [Windcamp Gipsy] | -26 | 0 | 1797 km |
| 1.1 | 5.2887 MHz | 21:36 - 22:06 | 2.508V  | [Windcamp Gipsy] | -23 | 0 | 3898 km |
| 1.1 | 7.0401 MHz | 19:38 - 20:08 | 2.508V  | [Windcamp Gipsy] | -21 | 0 | 2043 km |
| 1.1 | 10.1402 MHz  | 16:56 - 17:26 | 2.508V  | [Windcamp Gipsy] | -4  | 0 | 2849 km |
| 1.1 | 14.0971 MHz  | 14:34 - 15:02 | 2.508V  | [Windcamp Gipsy] | -6  | 0 | 1721 km |

### [PCB version 2.0](https://github.com/IgrikXD/WSPR-beacon/releases/tag/wspr-beacon-pcb-2.0) with SN74ACT244PWR buffer amplifier:

| Firmware version | TX frequency | TX time (CET) | Used antenna | SNR | Drift | Max distance to receiver |
|---|---|---|---|-----|---|---|
| 1.1 | 5.2887 MHz | 22:10 - 22:40 | [Windcamp Gipsy] | -19 | 0 | 3898 km |
| 1.1 | 7.0401 MHz | 20:14 - 20:44 | [Windcamp Gipsy] | -13 | 0 | 2849 km |
| 1.1 | 10.1402 MHz  | 16:16 - 16:46 | [Windcamp Gipsy] | -6  | 0 | 2849 km |
| 1.1 | 14.0971 MHz  | 13:40 - 14:10 | [Windcamp Gipsy] | -19 | 0 | 3898 km |

## Device testing reports from users

This section provides information about the device's performance during long-distance WSPR message transmission based on real user feedback.

### [PCB version 1.0](https://github.com/IgrikXD/WSPR-beacon/releases/tag/wspr-beacon-1.0) with BS170 field-effect transistor amplifier:

| Reporter | Firmware version | TX frequency | PA bias | Used antenna | SNR | Drift | Max distance to receiver  |
|---|---|---|---|---|-----|---|---|
| [KD9MXZ](https://www.qrz.com/db/kd9mxz) | 1.1 | 14.0971 MHz  | 2.610V  | [PackTenna Mini Random Wire] | -28 | 0 | 4618 km |

### [PCB version 2.0](https://github.com/IgrikXD/WSPR-beacon/releases/tag/wspr-beacon-pcb-2.0) with SN74ACT244PWR buffer amplifier:

| Reporter | Firmware version | TX frequency  | Used antenna | SNR | Drift | Max distance to receiver  |
|---|---|---|---|-----|---|---|
| [HF2N](https://www.qrz.com/db/hf2n) | 1.1 | 14.097061 MHz | Ground-mounted 1/4-wave vertical antenna | -24 | 0 | 17729 km |
| [HF2N](https://www.qrz.com/db/hf2n) | 1.1 | 14.096995 MHz | End-Fed Half Wave antenna, 1:49 balun, approximately 20 meters long | -21 | 0 | 6545 km |
| [HF2N](https://www.qrz.com/db/hf2n) | 1.1 | 14.096977 MHz | Untuned telescopic antenna, approximately 5 meters tall | -34 | 0 | 3902 km |

If you would like to add the results of testing your WSPR beacon to this section, please send the following information to igor.nikolaevich.96@gmail.com:
- Amateur radio callsign;
- Version of the PCB used;
- Bias voltage of the BS170 transistor (_only for PCB version 1.0_);
- Version of the firmware used;
- Antenna used;
- List of spot information in .csv format;

[Windcamp Gipsy]: https://www.windcamp.cn/productinfo/372468.html
[PackTenna Mini Random Wire]: https://www.packtenna.com/store/p1/PackTenna_Mini_Random_Wire_Antenna_%289%3A1_UNUN%29.html#/

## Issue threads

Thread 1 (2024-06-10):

Documentatuon of its *range* capabilities is needed...

davidbuzz, 2024-06-10:
Eg, it was recieved by a wspr reciever X km away when conneted to X antenna and transmitting on frequency X

IgrikXD, 2024-06-10:
> Eg, it was recieved by a wspr reciever X km away when conneted to X antenna and transmitting on frequency X

Such documentation is completely uninformative. **With the same antenna and on the same frequency, two different people can get completely different results. Why is that?** This may be due to:

1. Different geographic locations of the two different transmitting beacons and their varying distances from the WSPR receivers;
2. Differences in transmission times (_propagation in some bands depends on the time of day_);
3. Differences in antenna setup - the same antenna can be tuned differently and installed in completely different conditions (_one is in an open field outside the city, the other in an urban area_);
4. Differences in output amplifier settings;
5. Differences in the filters used;

**Adding such information is only relevant as a report from a specific user, with a description of the equipment used and the transmission conditions.** I could conduct such tests, but their results would not guarantee that another user would be able to reproduce the same results.

However, I like your idea, and I will consider the possibility of adding a separate table with reports on the device's performance from real users in the future. Changes to such a table could be made via a Pull Request. **If you have ideas for an alternative implementation, I would be happy to consider them!**

davidbuzz, 2024-06-13:
Personally, I'm basically just trying to understand wether, for a given setup, I should expect 10meters range, 100meters range, 1kmrange, 10km range , 100km range. :-)

IgrikXD, 2024-06-13:
> Personally, I'm basically just trying to understand wether, for a given setup, I should expect 10meters range, 100meters range, 1kmrange, 10km range , 100km range. :-)

I plan to conduct field tests outside the city soon on the 7 and 14 MHz bands. Once I have the results, I will definitely share them! I think I will add an additional table of the obtained results to the repository.

IgrikXD, 2024-07-16:
**Device test report added:** https://github.com/IgrikXD/WSPR-beacon/blob/master/Device-test-report.md

Closed 2024-07-16.

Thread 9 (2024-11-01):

Why random frequency on each transmission cycle?

danielcharrua, 2024-11-01:
Hello, I'm trying to understand this:

> Each transmission cycle is performed at a randomly selected frequency within a range of +/- 100 Hz from the center frequency.

Can you explain why?
Thank you.

IgrikXD, 2024-12-24:
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

Good afternoon! This is done to **prevent potential collisions with other WSPR transmitters operating on the same frequency** as the one used by your device for message transmission. According to the standard, WSPR messages can be transmitted within a 200 Hz bandwidth for each operational band. Using the central operating frequency, we randomly select a transmission frequency within ±100 Hz of the central frequency during each transmission cycle. This approach ensures reliable transmission of a series of WSPR messages, even in cases where some transmitted messages collide with signals from other WSPR beacons.

Best regards, Ihar Yatsevich

Closed 2024-12-31.

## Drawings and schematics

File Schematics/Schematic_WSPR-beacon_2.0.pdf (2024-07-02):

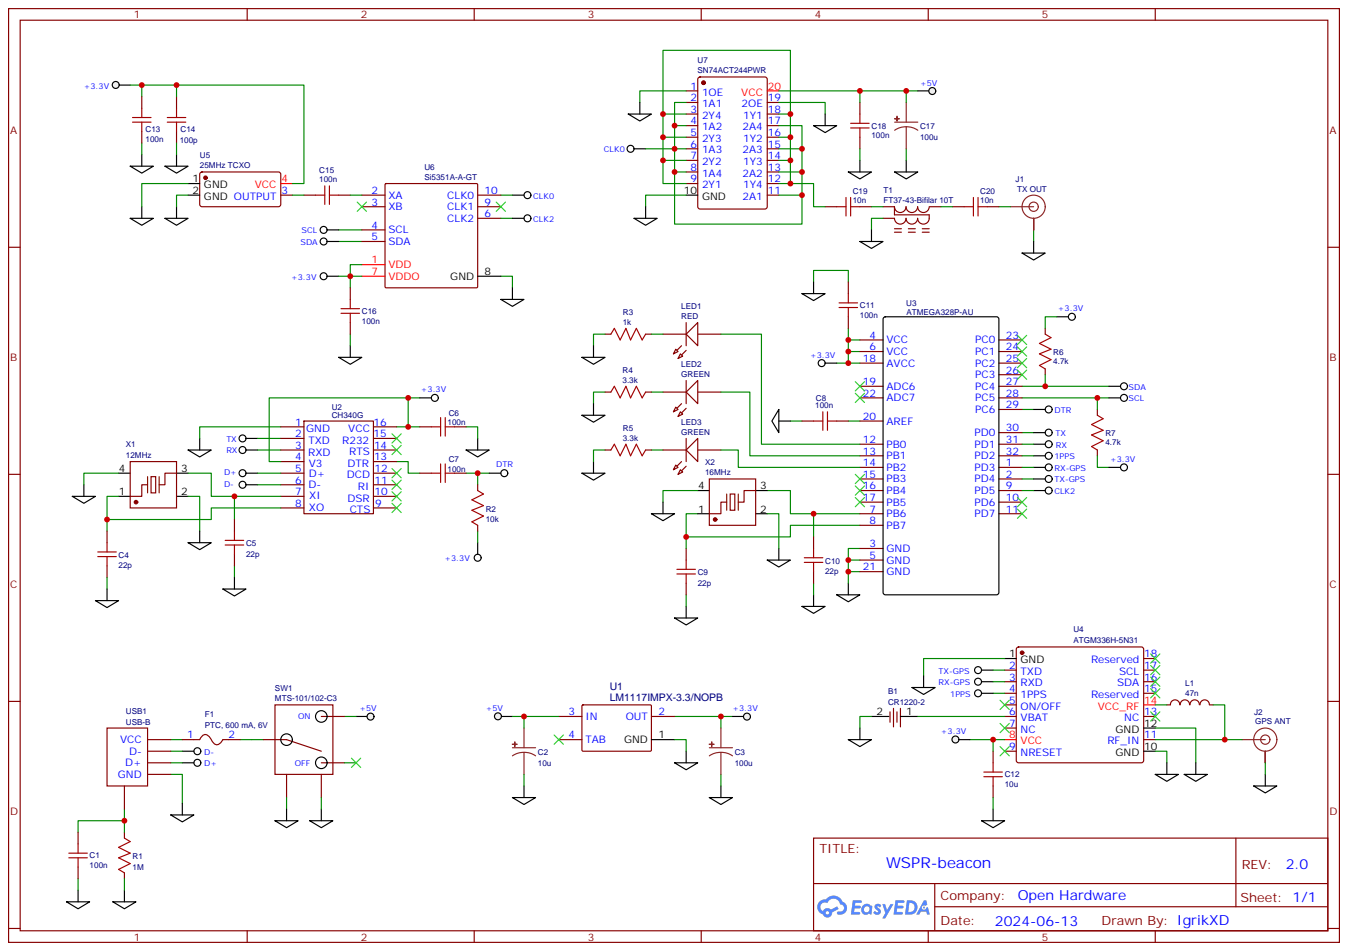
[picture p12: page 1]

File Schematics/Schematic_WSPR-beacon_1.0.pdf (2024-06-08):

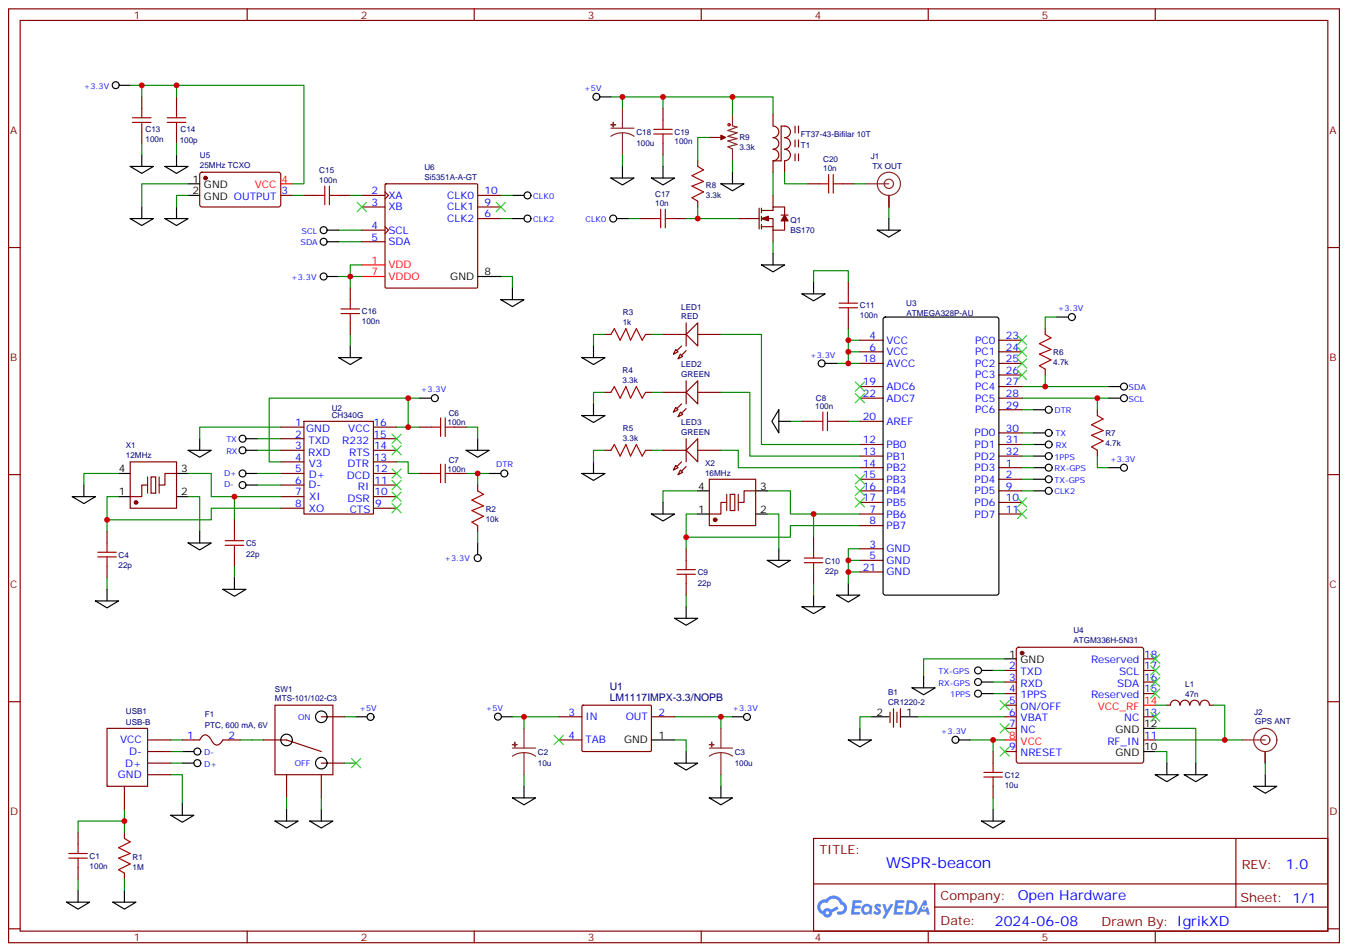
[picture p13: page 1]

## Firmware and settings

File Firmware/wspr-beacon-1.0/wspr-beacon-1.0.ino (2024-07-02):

#include <JTEncode.h>
#include <si5351.h>
#include <TimeLib.h>
#include <TinyGPS++.h>
#include <SoftwareSerial.h>

#define FIRMWARE_VERSION 1.0

//******************************************************************
//                      WSPR configuration
//******************************************************************
// WSPR protocol configuration
#define WSPR_TONE_SPACING          146
#define WSPR_DELAY                 683
#define WSPR_MESSAGE_BUFFER_SIZE   255

// WSPR center frequency in Hz
// #define WSPR_DEFAULT_FREQ       137500ULL    // 0.1375 MHz - 2200m
// #define WSPR_DEFAULT_FREQ       475700ULL    // 0.4757 MHz - 600m
// #define WSPR_DEFAULT_FREQ       1838100ULL   // 1.8381 MHz - 160m
// #define WSPR_DEFAULT_FREQ       3570100ULL   // 3.5701 MHz - 80m
// #define WSPR_DEFAULT_FREQ       5288700ULL   // 5.2887 MHz - 60m
// #define WSPR_DEFAULT_FREQ       7040100ULL   // 7.0401 MHz - 40m
// #define WSPR_DEFAULT_FREQ       10140200ULL  // 10.1402 MHz - 30m
// #define WSPR_DEFAULT_FREQ       14097100ULL  // 14.0971 MHz - 20m
// #define WSPR_DEFAULT_FREQ       18106100ULL  // 18.1061 MHz - 17m
// #define WSPR_DEFAULT_FREQ       21096100ULL  // 21.0961 MHz - 15m
// #define WSPR_DEFAULT_FREQ       24926100ULL  // 24.9261 MHz - 12m
#define WSPR_DEFAULT_FREQ       28126100ULL  // 28.1261 MHz - 10m
// #define WSPR_DEFAULT_FREQ       50294500ULL  // 50.2945 MHz - 6m
// #define WSPR_DEFAULT_FREQ       144490000ULL  // 144.4900 MHz - 2m

// WSPR message parameters
#define WSPR_CALL                 "XX0YYY"
#define WSPR_DBM                   23

char WSPR_QTH_LOCATOR[5];

//******************************************************************
//                      Hardware defines
//******************************************************************
#define TX_LED_PIN                 8
#define POWER_ON_LED_PIN           10
#define SERIAL_PORT_BAUDRATE       115200
#define RESET_DELAY                1000

#define SI5351_CAL_FACTOR          2000
#define SI5351_I2C_ADDRESS         0x60

#define GPS_RX_PIN                 4
#define GPS_TX_PIN                 3
#define GPS_BAUDRATE               9600
#define GPS_SERIAL_READ_DURATION   1200
#define GPS_STATUS_LED_PIN         9
#define GPS_INIT_MAX_TIME          5000
#define GPS_INIT_DELAY             500
#define GPS_SYNC_ATTEMPTS          10
#define GPS_SYNC_DELAY             10000

//******************************************************************
//                      Global variables
//******************************************************************
uint8_t tx_buffer[WSPR_MESSAGE_BUFFER_SIZE];
Si5351 si5351(SI5351_I2C_ADDRESS);

void(* resetHardware) (void) = 0;

//******************************************************************
//                      Function Prototypes
//******************************************************************
void initializeLEDs();
void initializeGPSSerialConnection(SoftwareSerial& gpsSerial);
void initializeSI5351();
void synchronizeGPSData();
bool trySyncGPSData(SoftwareSerial& gpsSerial, TinyGPSPlus& gps);
void setQTHLocator(const TinyGPSPlus& gps);
void encodeWSPRMessage();
void transmitWSPRMessage();
void printCurrentDateTime();
void printCurrentLocation(const TinyGPSPlus& gps);
void printDelimiter();
void printTransmissionDetails();
void printWSPRConfiguration();

//******************************************************************
//                      Function Definitions
//******************************************************************

void initializeLEDs()
{  
    pinMode(TX_LED_PIN, OUTPUT);
    digitalWrite(TX_LED_PIN, LOW);

    pinMode(POWER_ON_LED_PIN, OUTPUT);
    digitalWrite(POWER_ON_LED_PIN, HIGH);
    
    pinMode(GPS_STATUS_LED_PIN, OUTPUT);
    digitalWrite(GPS_STATUS_LED_PIN, LOW);
}

void initializeGPSSerialConnection(SoftwareSerial& gpsSerial)
{   
    gpsSerial.begin(GPS_BAUDRATE);
    
    const unsigned long startTime{millis()};
    while (gpsSerial.available() == false && millis() <= startTime + GPS_INIT_MAX_TIME)
    {
        delay(GPS_INIT_DELAY);
    }

    if (gpsSerial.available() == false)
    {
        Serial.println(F("- Unable to get data from GPS module! -"));
        delay(RESET_DELAY);
        resetHardware();
    }
}

void initializeSI5351()
{
    if (si5351.init(SI5351_CRYSTAL_LOAD_8PF, 0, SI5351_CAL_FACTOR))
    {
        Serial.println(F("- SI5351 successfully initialized! -"));
        // Set CLK0 as TX OUT
        si5351.drive_strength(SI5351_CLK0, SI5351_DRIVE_6MA);
        si5351.output_enable(SI5351_CLK0, 0);
    }
    else
    {
        Serial.println(F("- SI5351 initialization error! -"));
        Serial.print(F("- Ensure that the SI5351 has an I2C address 0x"));
        Serial.print(SI5351_I2C_ADDRESS, HEX);
        Serial.println(F(" -"));
        delay(RESET_DELAY);
        resetHardware();
    }

}

void synchronizeGPSData()
{
    SoftwareSerial gpsSerial{GPS_RX_PIN, GPS_TX_PIN};

    initializeGPSSerialConnection(gpsSerial);

    Serial.println(F("- GPS data sync -"));
    
    TinyGPSPlus gps;
    uint8_t syncAttemps{1};
    bool dataSynchronized{trySyncGPSData(gpsSerial, gps)};
    while (dataSynchronized == false && syncAttemps < GPS_SYNC_ATTEMPTS)
    {
        Serial.print(F("- Sync attempt "));
        Serial.print(syncAttemps);
        Serial.println(F(" failed! -"));
        Serial.println(F("- Waiting for the next sync attempt... -"));
        delay(GPS_SYNC_DELAY);
        dataSynchronized = trySyncGPSData(gpsSerial, gps);
        ++syncAttemps;
    }

    if (dataSynchronized)
    {
        Serial.print(F("- Date & time (GMT) synchronized by GPS: "));
        printCurrentDateTime();
        Serial.println(F(" -"));
        Serial.print(F("- Location synchronized by GPS: "));
        printCurrentLocation(gps);
        Serial.println(F(" -"));
        Serial.print(F("- QTH locator: "));
        Serial.print(WSPR_QTH_LOCATOR);
        Serial.println(F(" -"));
    }
    else
    {   
        Serial.println(F("- GPS data sync not available! -"));
        Serial.println(F("- Transmitting a WSPR message without time & location sync is impossible! -"));
        Serial.println(F("- Check your GPS antenna and try again! -"));
        delay(RESET_DELAY);
        resetHardware();
    }
}

bool trySyncGPSData(SoftwareSerial& gpsSerial, TinyGPSPlus& gps)
{ 
    const unsigned long startTime{millis()};
    while (millis() - startTime < GPS_SERIAL_READ_DURATION) 
    {
        while (gpsSerial.available())
            gps.encode(gpsSerial.read());
    }

    if (gps.time.isValid() && gps.date.isValid() && gps.location.isValid()){
        setTime(gps.time.hour(), gps.time.minute(), gps.time.second(), gps.date.day(), gps.date.month(), gps.date.year());
        setQTHLocator(gps);
        digitalWrite(GPS_STATUS_LED_PIN, HIGH);
        return true;
    }
    
    digitalWrite(GPS_STATUS_LED_PIN, LOW);
    return false; 
}

void setQTHLocator(const TinyGPSPlus& gps) {
    float latitude{gps.location.lat() + 90.0};
    float longitude{gps.location.lng() + 180.0};

    WSPR_QTH_LOCATOR[0] = 'A' + (longitude / 20);
    WSPR_QTH_LOCATOR[1] = 'A' + (latitude / 10);

    WSPR_QTH_LOCATOR[2] = '0' + (uint8_t)(longitude / 2) % 10;
    WSPR_QTH_LOCATOR[3] = '0' + (uint8_t)(latitude) % 10;

    WSPR_QTH_LOCATOR[4] = '\0';
}

void encodeWSPRMessage()
{
    memset(tx_buffer, 0, WSPR_MESSAGE_BUFFER_SIZE);
    
    JTEncode jtencode;
    jtencode.wspr_encode(WSPR_CALL, WSPR_QTH_LOCATOR, WSPR_DBM, tx_buffer);
}

void transmittWsprMessage()
{
    Serial.println(F("- WSPR TX ON -"));

    digitalWrite(TX_LED_PIN, HIGH);
  
    // WSPR message transmission at each function call is performed on a randomly selected 
    // frequency within the range of +/- 100 Hz from the center frequency.
    const unsigned long transmissionFrequency{WSPR_DEFAULT_FREQ + random(-100, 101)};

    Serial.print(F("- Transmisson frequency: "));
    Serial.print(transmissionFrequency / 1000000.0, 6);
    Serial.println(F(" MHz -"));

    si5351.output_enable(SI5351_CLK0, 1);

    for(uint8_t i{0}; i < WSPR_SYMBOL_COUNT; ++i)
    {
        si5351.set_freq(transmissionFrequency * 100ULL + (tx_buffer[i] * WSPR_TONE_SPACING), SI5351_CLK0);
        delay(WSPR_DELAY);
    }

    si5351.output_enable(SI5351_CLK0, 0);

    Serial.println(F("- WSPR TX OFF -"));
    digitalWrite(TX_LED_PIN, LOW);
}

void printCurrentDateTime()
{
    Serial.print(day());
    Serial.print(F("/"));
    Serial.print(month());
    Serial.print(F("/"));
    Serial.print(year());
    Serial.print(F(" "));
    Serial.print(hour());
    Serial.print(F(":"));
    Serial.print(minute());
    Serial.print(F(":"));
    Serial.print(second());
}

void printCurrentLocation(const TinyGPSPlus& gps)
{
    Serial.print(gps.location.lat(), 4);
    Serial.print(F(", "));
    Serial.print(gps.location.lng(), 4);
}

void printDelimiter()
{
    Serial.println(F("********************************************"));
}

void printTransmissionDetails() {
    Serial.print(F("- Start of transmission time (GMT): "));
    printCurrentDateTime();
    Serial.println(F(" -"));
    Serial.print(F("- WSPR message: "));
    Serial.print(WSPR_CALL);
    Serial.print(F(" "));
    Serial.print(WSPR_QTH_LOCATOR);
    Serial.print(F(" "));
    Serial.print(WSPR_DBM);
    Serial.println(F(" -"));
}

void printWSPRConfiguration() {
    printDelimiter();
    Serial.println(F("[ WSPR BEACON ]"));
    Serial.print(F("- Firmware version: "));
    Serial.print(FIRMWARE_VERSION);
    Serial.println(F(" -"));
    Serial.print(F("- Working frequency: "));
    Serial.print(WSPR_DEFAULT_FREQ / 1000000.0, 6);
    Serial.println(F(" MHz -"));
    printDelimiter();
}

void setup()
{
    initializeLEDs();

    Serial.begin(SERIAL_PORT_BAUDRATE); 
    while (!Serial);

    printWSPRConfiguration();
    initializeSI5351();
    synchronizeGPSData();

    printDelimiter();
    Serial.println(F("- Entering WSPR TX loop..."));
    printDelimiter();

    encodeWSPRMessage();
    randomSeed(millis());
}

void loop()
{
    if(second() == 0 && minute() % 2 == 0)
    {
        printTransmissionDetails();
        transmittWsprMessage();
        printDelimiter();
        synchronizeGPSData();
        printDelimiter();
    }
}

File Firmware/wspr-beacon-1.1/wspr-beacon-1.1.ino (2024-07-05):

#include <JTEncode.h>
#include <si5351.h>
#include <SoftwareSerial.h>
#include <TimeLib.h>
#include <TinyGPS++.h>

#define FIRMWARE_VERSION 1.1

//******************************************************************
//                      WSPR configuration
//******************************************************************
// WSPR protocol configuration
#define WSPR_TONE_SPACING          146
#define WSPR_DELAY                 683
#define WSPR_MESSAGE_BUFFER_SIZE   255

// WSPR center frequency in Hz
// #define WSPR_DEFAULT_FREQ       137500ULL    // 0.1375 MHz - 2200m
// #define WSPR_DEFAULT_FREQ       475700ULL    // 0.4757 MHz - 600m
// #define WSPR_DEFAULT_FREQ       1838100ULL   // 1.8381 MHz - 160m
// #define WSPR_DEFAULT_FREQ       3570100ULL   // 3.5701 MHz - 80m
// #define WSPR_DEFAULT_FREQ       5288700ULL   // 5.2887 MHz - 60m
// #define WSPR_DEFAULT_FREQ       7040100ULL   // 7.0401 MHz - 40m
// #define WSPR_DEFAULT_FREQ       10140200ULL  // 10.1402 MHz - 30m
// #define WSPR_DEFAULT_FREQ       14097100ULL  // 14.0971 MHz - 20m
// #define WSPR_DEFAULT_FREQ       18106100ULL  // 18.1061 MHz - 17m
// #define WSPR_DEFAULT_FREQ       21096100ULL  // 21.0961 MHz - 15m
// #define WSPR_DEFAULT_FREQ       24926100ULL  // 24.9261 MHz - 12m
#define WSPR_DEFAULT_FREQ       28126100ULL  // 28.1261 MHz - 10m
// #define WSPR_DEFAULT_FREQ       50294500ULL  // 50.2945 MHz - 6m
// #define WSPR_DEFAULT_FREQ       70092500ULL  // 70.0925 MHz - 4m
// #define WSPR_DEFAULT_FREQ       144490500ULL // 144.4905 MHz - 2m

// WSPR message parameters
#define WSPR_CALL                 "XX0YYY"
#define WSPR_DBM                   23

//******************************************************************
//                      Hardware defines
//******************************************************************
#define TX_LED_PIN                 8
#define POWER_ON_LED_PIN           10

#define SI5351_CAL_FACTOR          2000
#define SI5351_I2C_ADDRESS         0x60

#define GPS_RX_PIN                 4
#define GPS_TX_PIN                 3
#define GPS_BAUDRATE               9600
#define GPS_SERIAL_READ_DURATION   1200
#define GPS_STATUS_LED_PIN         9
#define GPS_INIT_MAX_TIME          5000
#define GPS_INIT_DELAY             500
#define GPS_SYNC_ATTEMPTS          10
#define GPS_SYNC_DELAY             10000

//******************************************************************
//                      Global variables
//******************************************************************
uint8_t tx_buffer[WSPR_MESSAGE_BUFFER_SIZE];
Si5351 si5351(SI5351_I2C_ADDRESS);
uint64_t transmissionFrequency;

void(* resetHardware) (void) = 0;

//******************************************************************
//                      Function prototypes
//******************************************************************
void encodeWSPRMessage(const TinyGPSPlus& gpsDataObj);
void errorLEDIndicationAndReboot();
void initializeGPSSerialConnection(SoftwareSerial& gpsSerial);
void initializeLEDs();
void initializeSI5351();
void setQTHLocator(const TinyGPSPlus& gpsDataObj, char qthLocator[]);
void setTransmissionFrequency();
void synchronizeDateTime(TinyGPSPlus& gpsDataObj);
void transmitWSPRMessage();
bool trySyncGPSData(SoftwareSerial& gpsSerial, TinyGPSPlus& gpsDataObj);

//******************************************************************
//                      Function definitions
//******************************************************************
void encodeWSPRMessage(const TinyGPSPlus& gpsDataObj)
{
    memset(tx_buffer, 0, WSPR_MESSAGE_BUFFER_SIZE);
    
    char qthLocator[5];
    setQTHLocator(gpsDataObj, qthLocator);

    JTEncode jtencode;
    jtencode.wspr_encode(WSPR_CALL, qthLocator, WSPR_DBM, tx_buffer);
}

void errorLEDIndicationAndReboot()
{
    // Turn off all the green LEDs (GPS, ON)
    digitalWrite(POWER_ON_LED_PIN, LOW);
    digitalWrite(GPS_STATUS_LED_PIN, LOW);

    // Flash the red LED (TX) three times
    for (uint8_t i{0}; i < 3; ++i) {
        digitalWrite(TX_LED_PIN, HIGH);
        delay(500);
        digitalWrite(TX_LED_PIN, LOW);
        delay(500);
    }

    resetHardware();
}

void initializeGPSSerialConnection(SoftwareSerial& gpsSerial)
{   
    gpsSerial.begin(GPS_BAUDRATE);
    
    const uint32_t startTime{millis()};
    while (gpsSerial.available() == false && millis() <= startTime + GPS_INIT_MAX_TIME)
        delay(GPS_INIT_DELAY);

    if (gpsSerial.available() == false)
        errorLEDIndicationAndReboot();
}

void initializeLEDs()
{  
    pinMode(TX_LED_PIN, OUTPUT);
    digitalWrite(TX_LED_PIN, LOW);

    pinMode(POWER_ON_LED_PIN, OUTPUT);
    digitalWrite(POWER_ON_LED_PIN, HIGH);
    
    pinMode(GPS_STATUS_LED_PIN, OUTPUT);
    digitalWrite(GPS_STATUS_LED_PIN, LOW);
}

void initializeSI5351()
{
    if (si5351.init(SI5351_CRYSTAL_LOAD_8PF, 0, SI5351_CAL_FACTOR))
        // Set CLK0 as TX OUT
        si5351.drive_strength(SI5351_CLK0, SI5351_DRIVE_8MA);
    else
        errorLEDIndicationAndReboot();
}

void setQTHLocator(const TinyGPSPlus& gpsDataObj, char qthLocator[]) {
    const float latitude{gpsDataObj.location.lat() + 90.0};
    const float longitude{gpsDataObj.location.lng() + 180.0};

    qthLocator[0] = 'A' + (longitude / 20);
    qthLocator[1] = 'A' + (latitude / 10);

    qthLocator[2] = '0' + (uint8_t)(longitude / 2) % 10;
    qthLocator[3] = '0' + (uint8_t)(latitude) % 10;

    qthLocator[4] = '\0';
}

void setTransmissionFrequency()
{
    // WSPR message transmission at each transmitWSPRMessage() function call is performed on 
    // a randomly selected frequency within the range of +/- 100 Hz from the center frequency
    transmissionFrequency = (WSPR_DEFAULT_FREQ + random(-100, 101)) * 100ULL;
}

void synchronizeDateTime(TinyGPSPlus& gpsDataObj)
{
    SoftwareSerial gpsSerial{GPS_RX_PIN, GPS_TX_PIN};

    initializeGPSSerialConnection(gpsSerial);
    
    uint8_t syncAttemps{1};
    bool dataSynchronized{trySyncGPSData(gpsSerial, gpsDataObj)};
    while (dataSynchronized == false && syncAttemps < GPS_SYNC_ATTEMPTS)
    {
        delay(GPS_SYNC_DELAY);
        dataSynchronized = trySyncGPSData(gpsSerial, gpsDataObj);
        ++syncAttemps;
    }

    if (dataSynchronized == false)
        errorLEDIndicationAndReboot();
}

void transmitWSPRMessage()
{
    digitalWrite(TX_LED_PIN, HIGH);

    si5351.output_enable(SI5351_CLK0, 1);

    for(uint8_t i{0}; i < WSPR_SYMBOL_COUNT; ++i)
    {
        si5351.set_freq(transmissionFrequency + (tx_buffer[i] * WSPR_TONE_SPACING), SI5351_CLK0);
        delay(WSPR_DELAY);
    }

    si5351.output_enable(SI5351_CLK0, 0);

    digitalWrite(TX_LED_PIN, LOW);
}
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

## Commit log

2024-05-15 Add GERBER & Schematic files
2024-05-15 Change power output info
2024-05-16 currentDateTime() memory optimization
2024-05-17 Update GERBER & Schematic
2024-05-17 Add BOM & resources info
    [BOM_WSPR-beacon_1.0.csv]
2024-05-20 Add info about GPS antenna
2024-05-20 Gerber update
2024-05-21 Fix TCXO routing error
    [BOM_WSPR-beacon_1.0.csv]
2024-05-21 Remove output_enable call at init stage
2024-05-22 Add AutoCAD files for side covers milling
    [WSPR-beacon-side-covers.dwg]
2024-05-22 Add info about I2C address of SI5351
2024-05-23 Replace AutoCAD side covers model to PCB gerbers
    [WSPR-beacon-side-covers.dwg]
2024-05-23 Update LED info
2024-05-23 Add assembly guide
2024-05-24 Add info about BS170 heatsink
2024-05-24 Add link to bifilar transformer soldering image
2024-05-25 #define use for reset delay
    [wsp-beacon.ino]
2024-05-25 Add info about fuse protection
2024-05-27 Fix transmisson frequency info
    [wsp-beacon.ino]
2024-05-27 Fix float number output
    [wsp-beacon.ino]
2024-05-27 Fix working frequency info
    [wsp-beacon.ino]
2024-05-27 Fix GPS data processing
    [wsp-beacon.ino]
2024-06-08 Swap RX/TX for GPS module
    [wsp-beacon.ino]
2024-06-08 Test device: replace cal factor for SI5351
    [wsp-beacon.ino]
2024-06-08 Update schematic & BOM
    [BOM_WSPR-beacon_1.0.csv]
2024-06-08 Add info about calibration alternative
2024-06-09 Add photos for assembly guide
2024-07-02 [PCB] Implementation of a new version of the PCB based on a buffer amplifier (#4)
    * Remove log messages, optimization
    * Remove info about log messages
    * Remove info about location sync
    * Update firmware version
    * Add gerber & schematic for PCB 2.0 revision
    * Add BOM for PCB 2.0 revision
    * Remove info about BS170 amplifier
    * Update info about PCB version
    * Update PCB version description
    * Revert back image deletion
    * Refactoring
    * Add link to PCB V1
    * Add info about QTH locator calculation
    * Refactoring
    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
    [BOM_WSPR-beacon_1.0.csv, BOM_WSPR-beacon_2.0.csv]
2024-07-02 [Firmware] Removing logging, fixing frequency for 2m band, indicating init errors using LED, removing QTH locator recalculation after each transmission cycle, adding hardware testing firmware (#5)
    * Revert deletion V1 firmware, file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
    [wspr-beacon-1.0.ino, wspr-beacon-1.1.ino, wspr-beacon-hardware-test.ino]
2024-07-05 Increase SI5351 output power (#6)
2024-07-16 [Testing] Adding information about testing the device for long-distance transmission (#3)
    * Add device test report draft
    * Add link to device test report
    * Change description, add SNR col
    * Update test report table
    * Split test table for PCB V1 and PCB V2
    * Add notice about antenna tuning
    * Add .kml report links
    * Change col name
    * Revert back changing col name
    * Add info about spot vizualization
    * Add info about power source
    * Add link to Windcamp Gipsy
    * Add antenna usage notice
    * Format fix
    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
2024-07-24 [Testing] Adding information about device testing from user KD9MXZ (#7)
    * Add user test report info
    * Add user contact info
    * Fix email link
    * Fix email link
    * Update test data
    * Add info about user tests results
2024-12-31 [Info] Adding current consumption information (#10)
    * Add current consumption info
    * Fix formatting
    * Information about purchasing devices
2025-01-01 [Info] Updating the link to the PCBWay project, adding donation information (#11)
    * Update PCBWay project link
    * Update funding info
2025-01-30 Update "Set up Arduino CLI" step to v2 (#22)
2025-01-30 Update firmware structure for correct CI processing (#23)
    [wspr-beacon-1.0.ino, wspr-beacon-1.1.ino, wspr-beacon-hardware-test.ino]
2025-02-01 [GitHub Actions] Fix app lint workflow: remove branch filter (#28)
2026-02-12 [GitHub Actions] Update branch filters in CI workflows to allow all branches (#42)
2026-03-13 [Testing] Adding information about device testing from user HF2N (#50)
2026-03-20 [Testing] Adding information about device testing from user HF2N (#53)
